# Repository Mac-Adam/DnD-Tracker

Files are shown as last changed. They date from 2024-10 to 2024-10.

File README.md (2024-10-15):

# DnD-Tracker
Repository for my resource tracker for D&amp;D
The premise of this project is to make keeping track of health, spell slots, and other resources quick and simple,
while preserving the vibe of an ttrpg.
It consists of 3 modules. One, keeps track of your health (3 led strips each one representing one digit of a 3 digit number)
Second one keeps track of your spell slots
The last one keeps track of whatever 20 resources you have, potions class features, magic items etc.
The rgb leds are driven by a 555 timer based circuit, this allows for controlling the color and brightness of the lights.
A standard 18650 cell is enough to power it for tens of hours (depending on the brightness level)
This project is not yet fully finished, the pcb and the files contain some errors that I haven't fixed yet.
The errors are:
  - Didn't reverse the logic of the LED ON button, insead of turning the leds off, it blasts them at full power
  - Transistors in one of the signal reperaters in the HP modules are switched (P is in flsae of N and N is in place of P)
  - The housing has misaligned mounting holes
## The Future
I might make the design modular, this would enable greater flexibility and probably would be cheaper.
Making the housing more practical and prettier.

If you want to build one of those yoursellf, but you encounter some problems with the provided files, contact me.

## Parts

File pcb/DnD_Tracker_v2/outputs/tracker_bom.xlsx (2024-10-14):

Qty | Designator | Footprint | Comment | LCSC Part #
3 | C1, C7, C11 | C2012 | 10n | C58456
141 | R3, R4, R5, R7, R8, R21, R29, R30, R32, R33, R35, R36, R38, R39, R41, R42, R61, R62, R64, R65, R67, R68, R89, R90, R93, R94, R96, R97, R113, R114, R115, R116, R125, R126, R128, R129, R138, R139, R140, R141, R144, R145, R147, R148, R152, R153, R155, R156, R158, R159, R167, R168, R170, R171, R173, R174, R179, R180, R182, R183, R185, R186, R188, R189, R191, R192, R194, R195, R203, R204, R206, R207, R217, R218, R220, R221, R231, R232, R234, R235, R245, R246, R257, R258, R260, R261, R269, R270, R272, R273, R283, R284, R286, R287, R297, R298, R300, R301, R311, R312, R320, R321, R323, R324, R326, R327, R329, R330, R332, R333, R335, R336, R338, R339, R341, R342, R344, R345, R347, R348, R350, R351, R353, R354, R356, R357, R359, R360, R362, R363, R365, R366, R368, R369, R371, R372, R374, R375, R379, R383, R387 | R0402 | 1k | C2991282
179 | R1, R2, R6, R9, R10, R11, R12, R13, R14, R15, R16, R28, R31, R34, R37, R40, R57, R58, R59, R60, R63, R66, R69, R70, R85, R86, R87, R88, R91, R92, R95, R98, R117, R118, R119, R120, R121, R122, R123, R124, R127, R134, R137, R142, R143, R146, R149, R150, R151, R154, R157, R160, R161, R162, R163, R164, R165, R166, R169, R172, R175, R176, R177, R178, R181, R184, R187, R190, R193, R196, R197, R198, R199, R200, R201, R202, R205, R208, R209, R210, R211, R212, R213, R214, R215, R216, R219, R222, R223, R224, R225, R226, R227, R228, R229, R230, R233, R236, R237, R238, R239, R240, R241, R242, R243, R244, R247, R248, R249, R250, R251, R252, R253, R254, R255, R256, R259, R262, R263, R264, R265, R266, R267, R268, R271, R274, R275, R276, R277, R278, R279, R280, R281, R282, R285, R288, R289, R290, R291, R292, R293, R294, R295, R296, R299, R302, R303, R304, R305, R306, R307, R308, R309, R310, R313, R314, R315, R316, R317, R318, R319, R322, R325, R328, R331, R334, R337, R340, R343, R346, R349, R352, R355, R358, R361, R364, R367, R370, R373 | R0402 | 1k5 | C409724
3 | C4, C8, C12 | C3216 | 470p | C309496
15 | U$4, U$36, U$99, U$148, U$166, U$181, U$196, U$211, U$224, U$239, U$249, U$262, U$277, U$292, U$307 | TSSOP14 | 74HC02PW,118 | C113211
27 | U$9, U$10, U$62, U$63, U$125, U$126, U$158, U$159, U$171, U$172, U$186, U$187, U$201, U$202, U$215, U$229, U$230, U$243, U$254, U$255, U$267, U$268, U$282, U$283, U$297, U$298, U$311 | SOT323 | BAW56W,115 | C426777
33 | U$5, U$6, U$57, U$59, U$100, U$101, U$150, U$153, U$167, U$168, U$182, U$183, U$197, U$198, U$212, U$213, U$225, U$226, U$240, U$241, U$250, U$251, U$263, U$264, U$278, U$279, U$293, U$294, U$308, U$309, U$332, U$336, U$340 | SOT323 | BAV99W | C2836068
3 | IC2, IC4, IC6 | SO08 | NE555 | C18164403
30 | U$7, U$8, U$60, U$61, U$102, U$124, U$154, U$157, U$169, U$170, U$184, U$185, U$199, U$200, U$214, U$220, U$227, U$228, U$242, U$248, U$252, U$253, U$265, U$266, U$280, U$281, U$295, U$296, U$310, U$316 | SMD_MICROSWITCH | YTSD003A0502502B | C2844401
69 | U$24, U$26, U$28, U$30, U$32, U$33, U$38, U$40, U$44, U$65, U$67, U$69, U$72, U$73, U$88, U$90, U$92, U$94, U$96, U$104, U$107, U$109, U$111, U$113, U$115, U$117, U$119, U$121, U$123, U$129, U$131, U$133, U$134, U$136, U$138, U$141, U$142, U$145, U$146, U$149, U$152, U$156, U$162, U$163, U$175, U$176, U$190, U$191, U$205, U$206, U$217, U$233, U$234, U$245, U$258, U$259, U$271, U$272, U$286, U$287, U$301, U$302, U$313, U$318, U$320, U$322, U$324, U$326, U$328 | BIG_SMD_LED | TC5050RGB_LED | C784540
30 | U$1, U$2, U$3, U$35, U$97, U$98, U$165, U$179, U$180, U$194, U$195, U$209, U$210, U$219, U$222, U$223, U$237, U$238, U$247, U$261, U$275, U$276, U$290, U$291, U$305, U$306, U$315, U$331, U$335, U$339 | SOT23 | SI2301 | C306861
51 | U$20, U$31, U$34, U$70, U$71, U$74, U$75, U$127, U$132, U$135, U$160, U$161, U$164, U$173, U$174, U$177, U$178, U$188, U$189, U$192, U$193, U$203, U$204, U$207, U$208, U$216, U$218, U$221, U$231, U$232, U$235, U$236, U$244, U$246, U$256, U$257, U$260, U$269, U$270, U$273, U$274, U$284, U$285, U$288, U$289, U$299, U$300, U$303, U$304, U$312, U$314 | SOT23 | SI2302S | C20628872

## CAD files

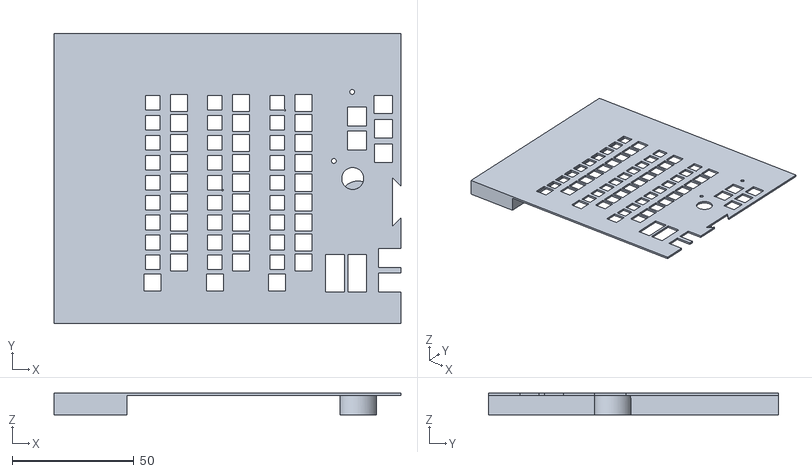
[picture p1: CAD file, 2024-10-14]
housing/top_right.stl
142.3 x 119.0 x 9.00

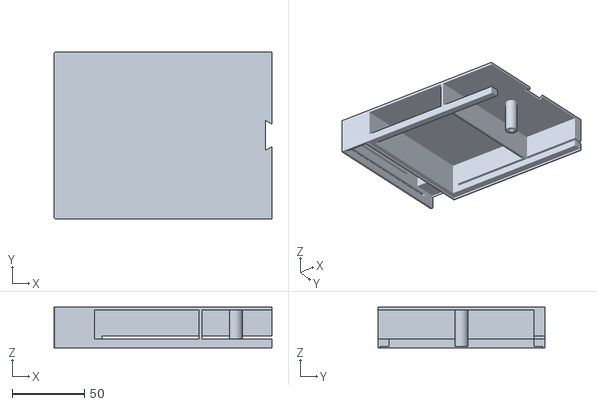
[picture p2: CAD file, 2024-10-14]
housing/base_right.stl
150.5 x 115.0 x 28.0

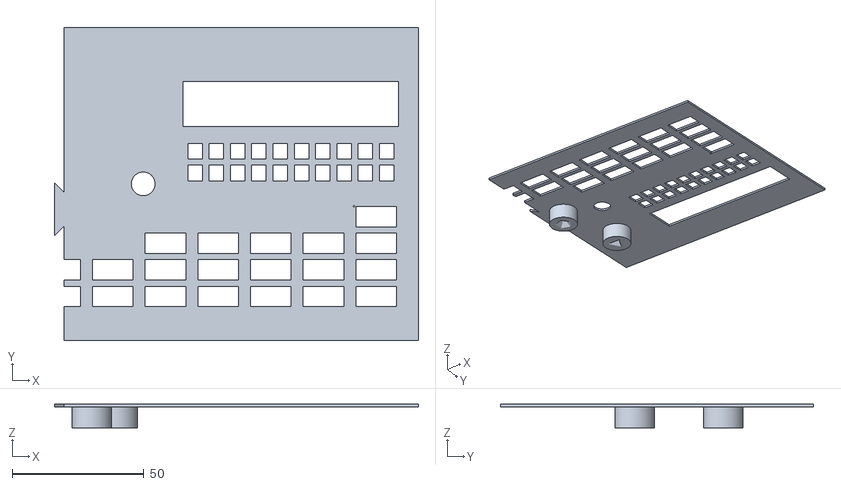
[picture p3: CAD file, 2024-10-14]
housing/top_left.stl
138.2 x 119.0 x 9.00

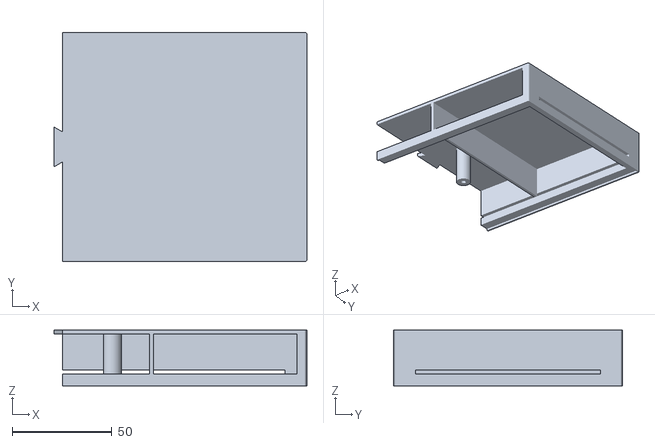
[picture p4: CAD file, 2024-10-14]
housing/base_left.stl
126.9 x 115.0 x 28.0

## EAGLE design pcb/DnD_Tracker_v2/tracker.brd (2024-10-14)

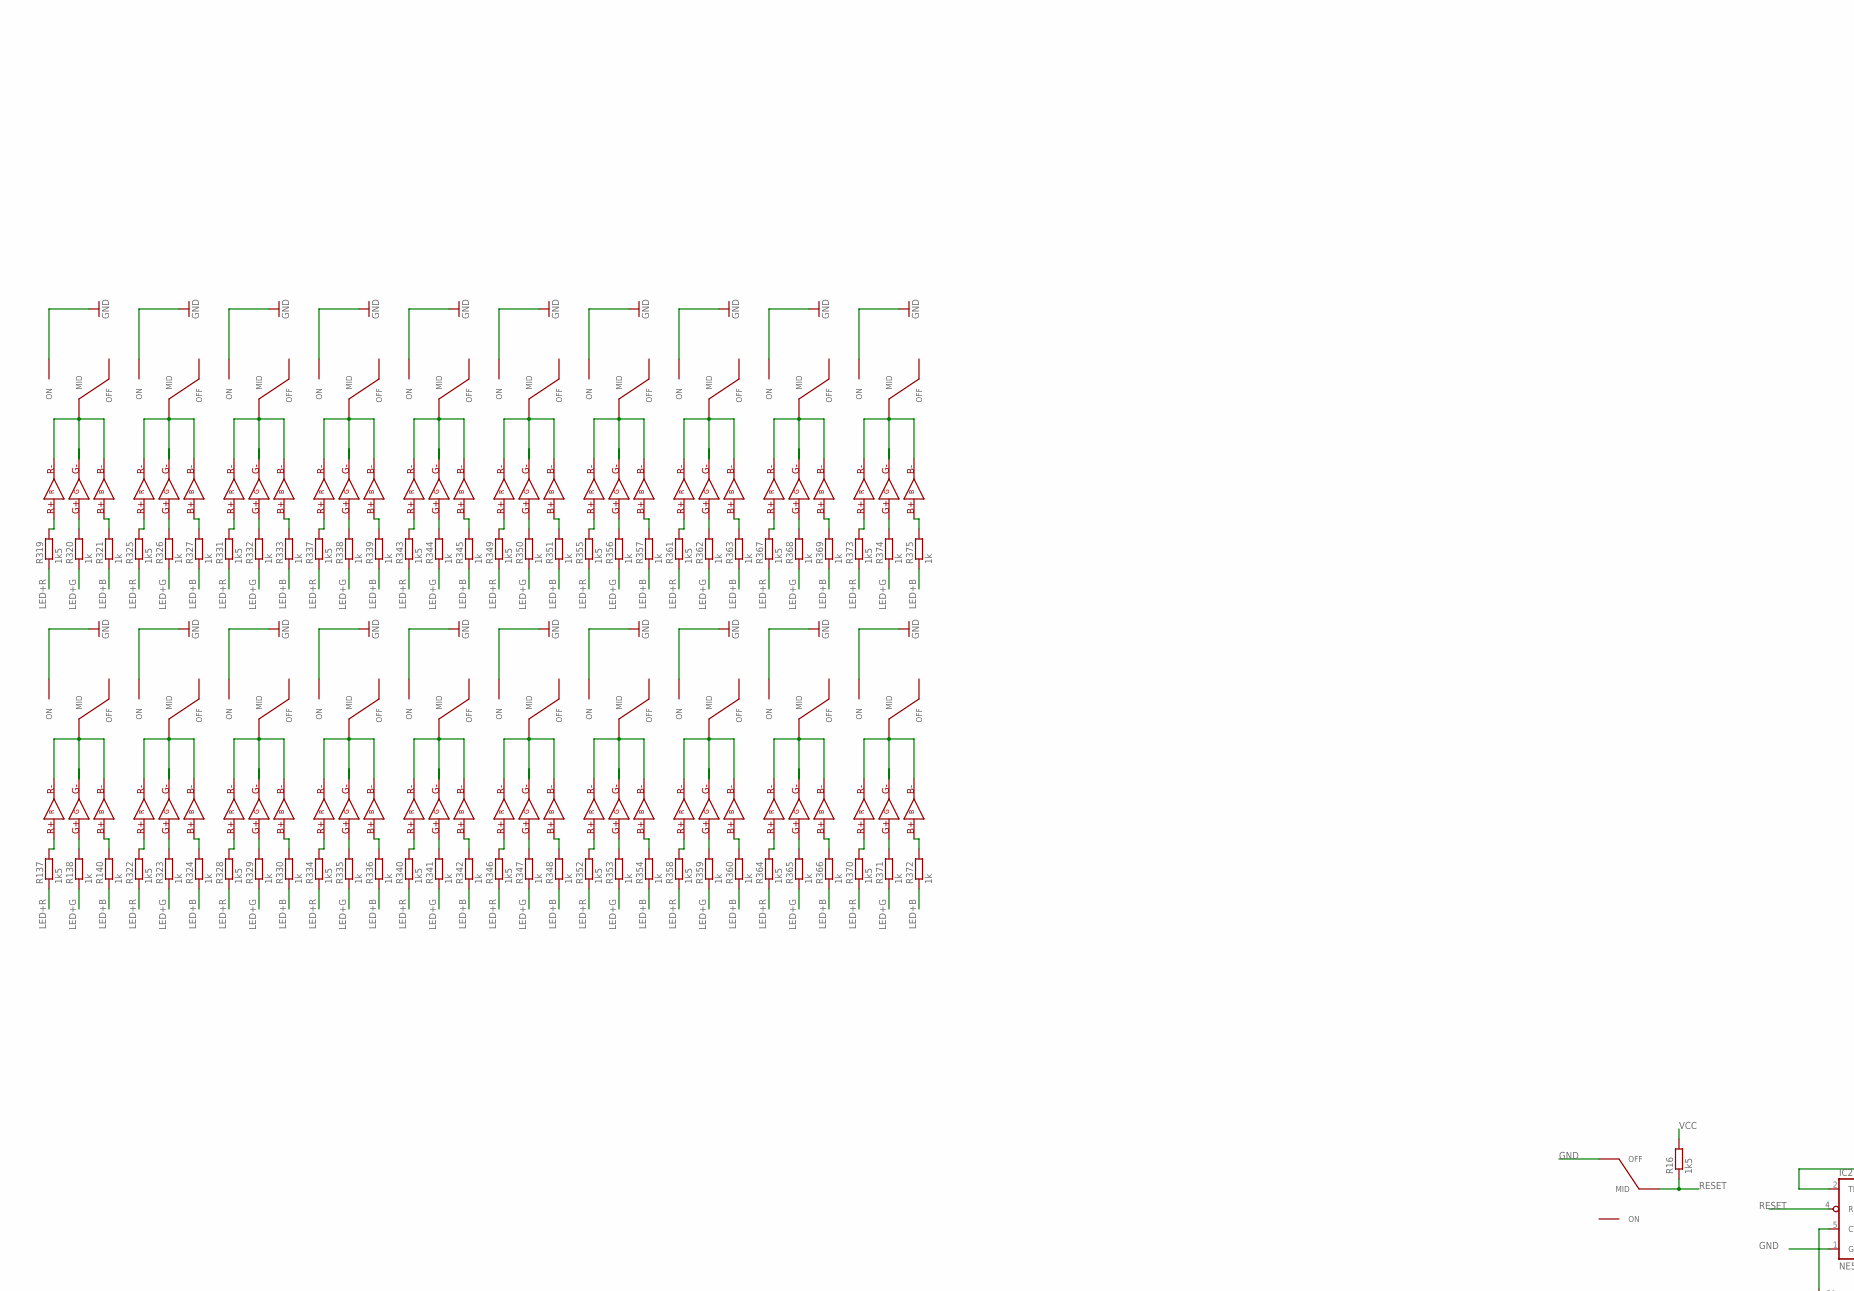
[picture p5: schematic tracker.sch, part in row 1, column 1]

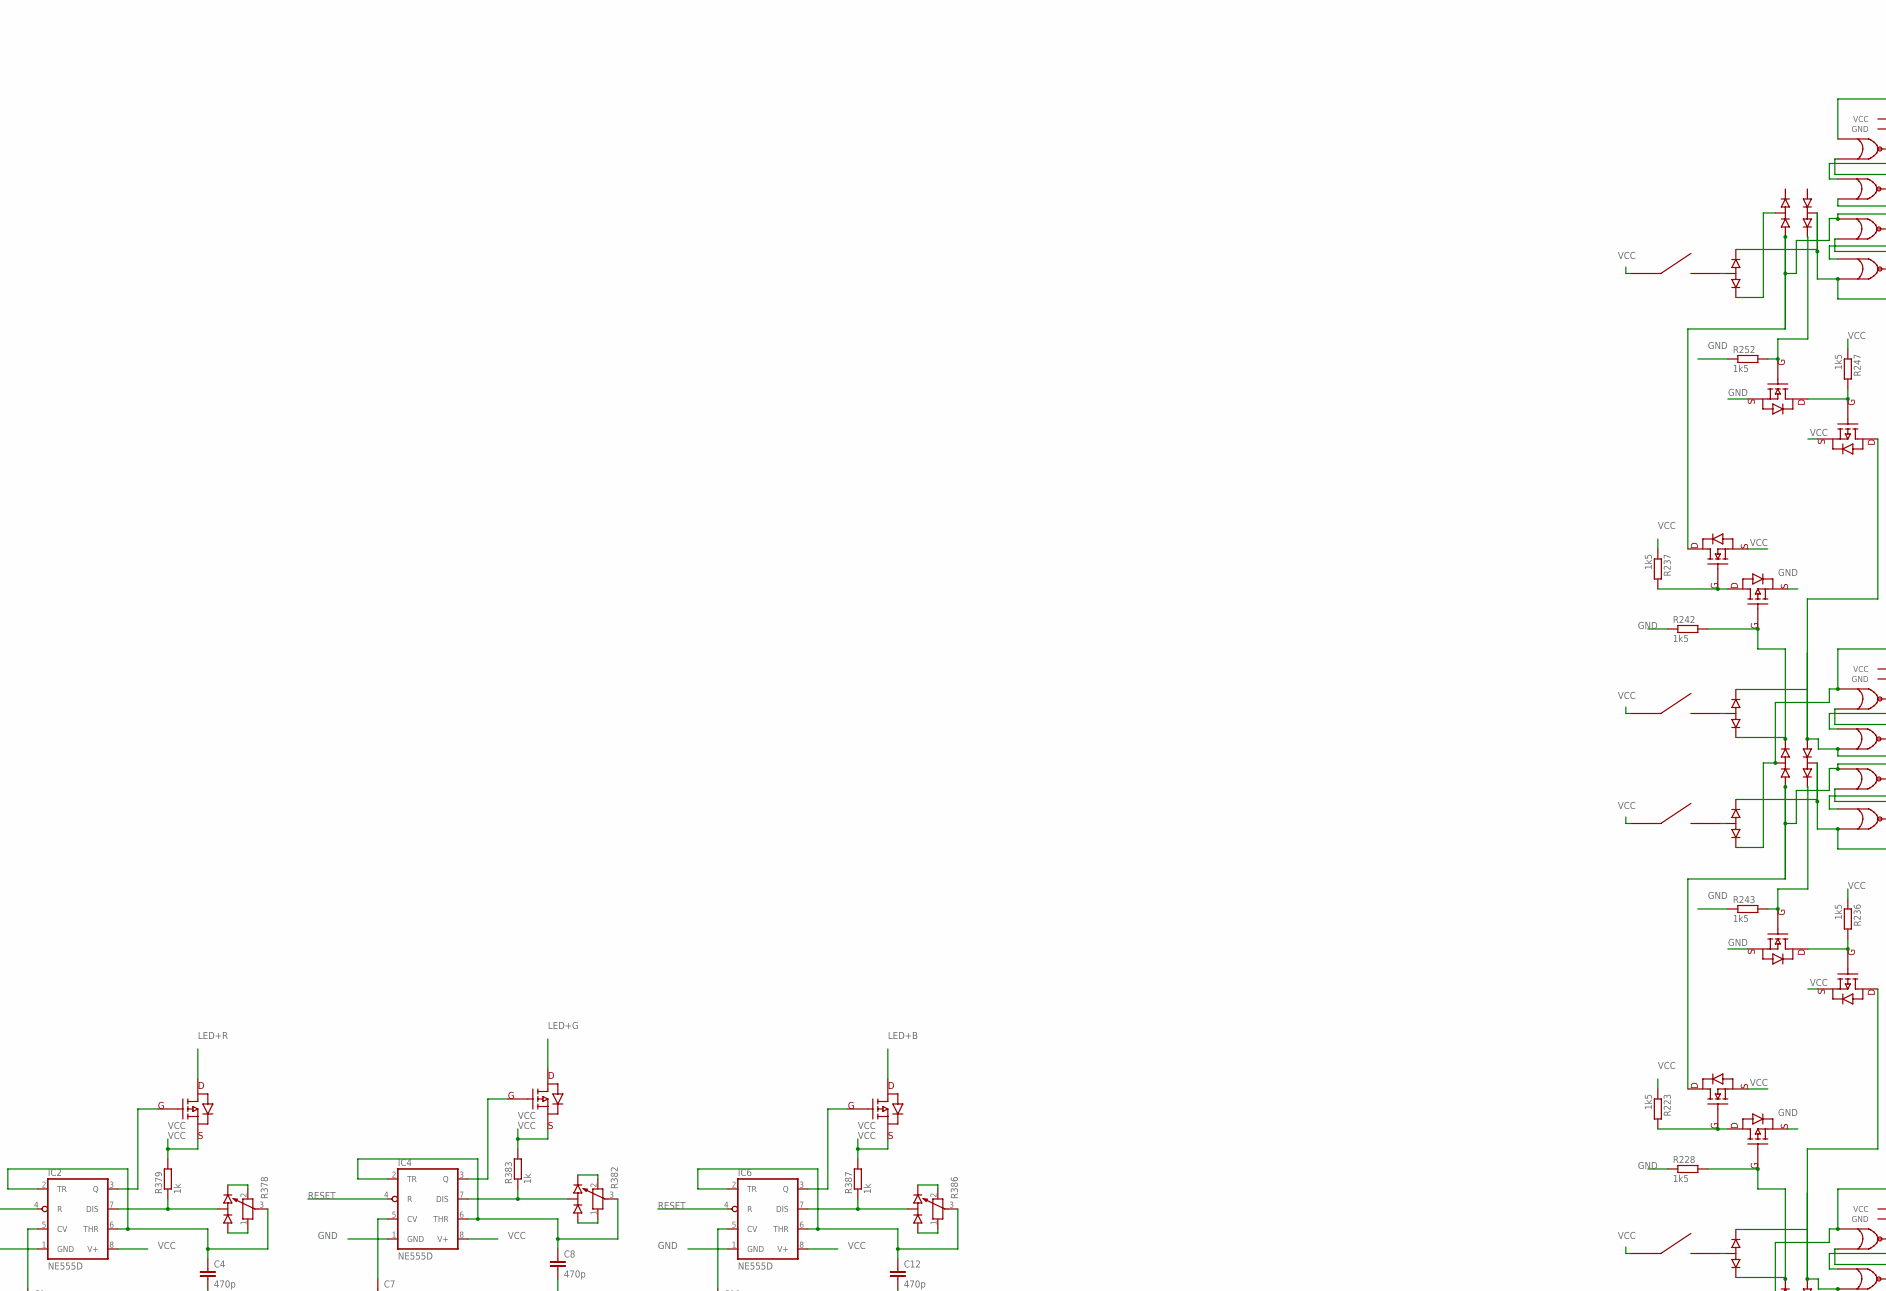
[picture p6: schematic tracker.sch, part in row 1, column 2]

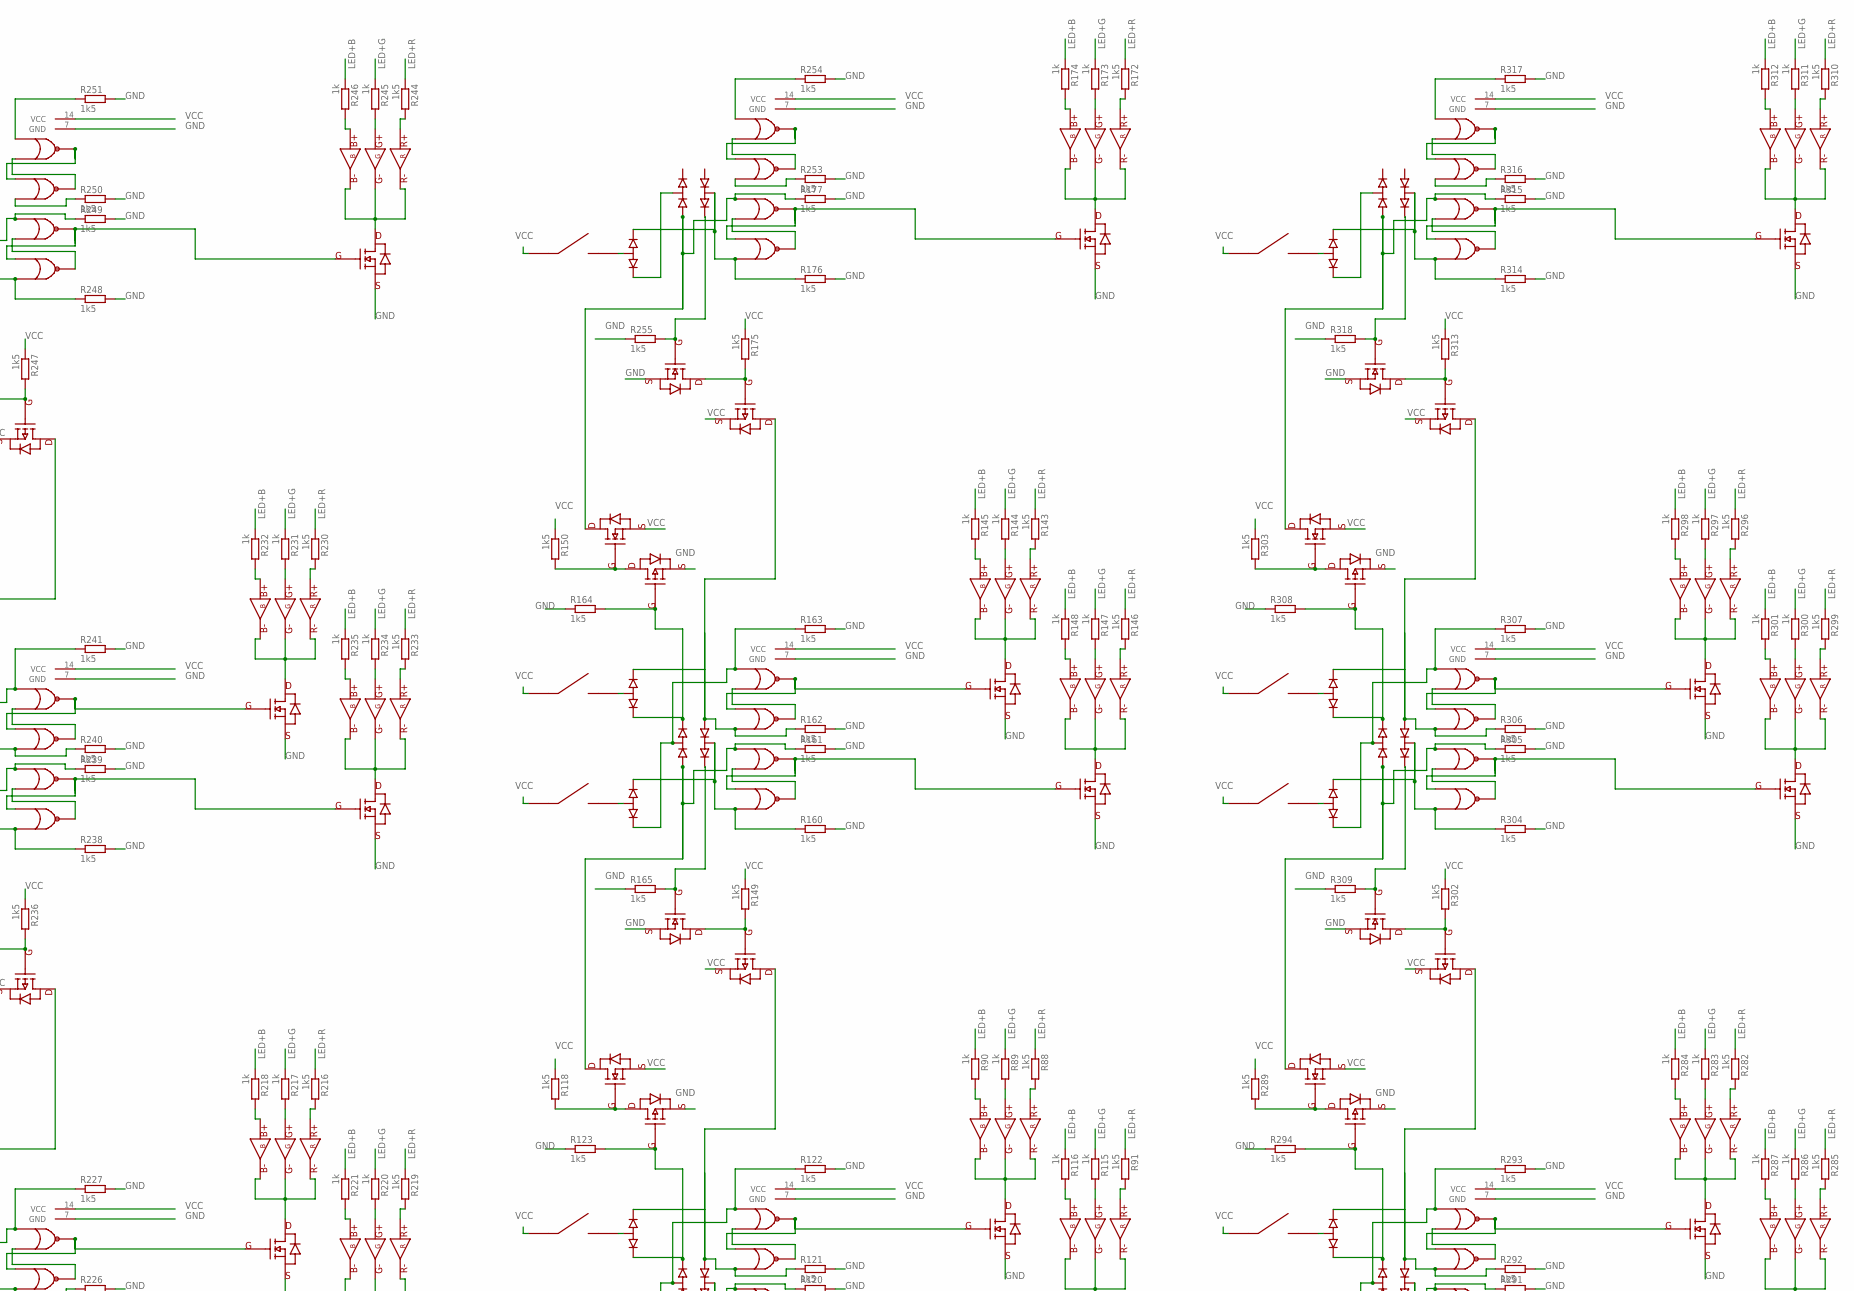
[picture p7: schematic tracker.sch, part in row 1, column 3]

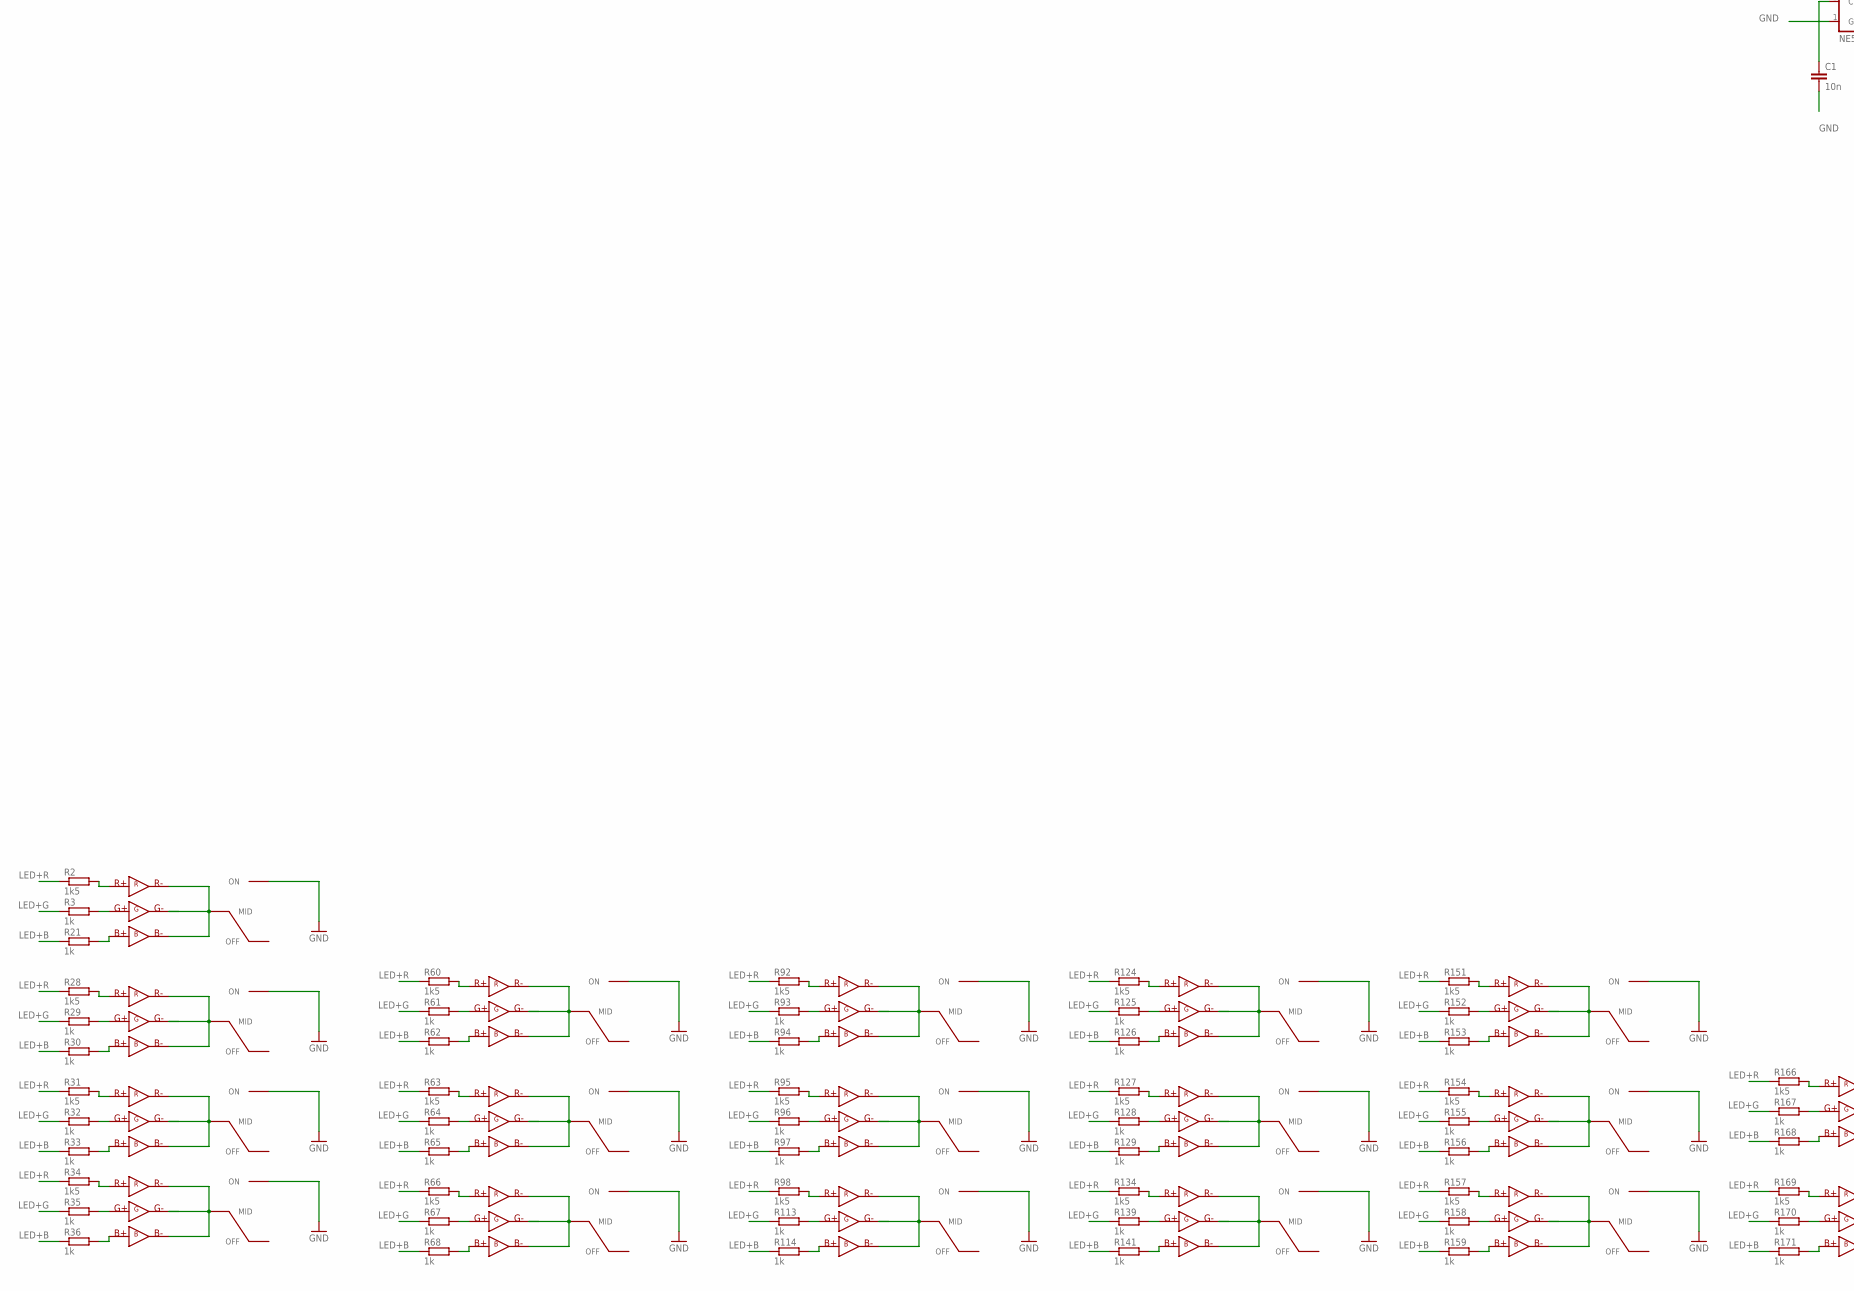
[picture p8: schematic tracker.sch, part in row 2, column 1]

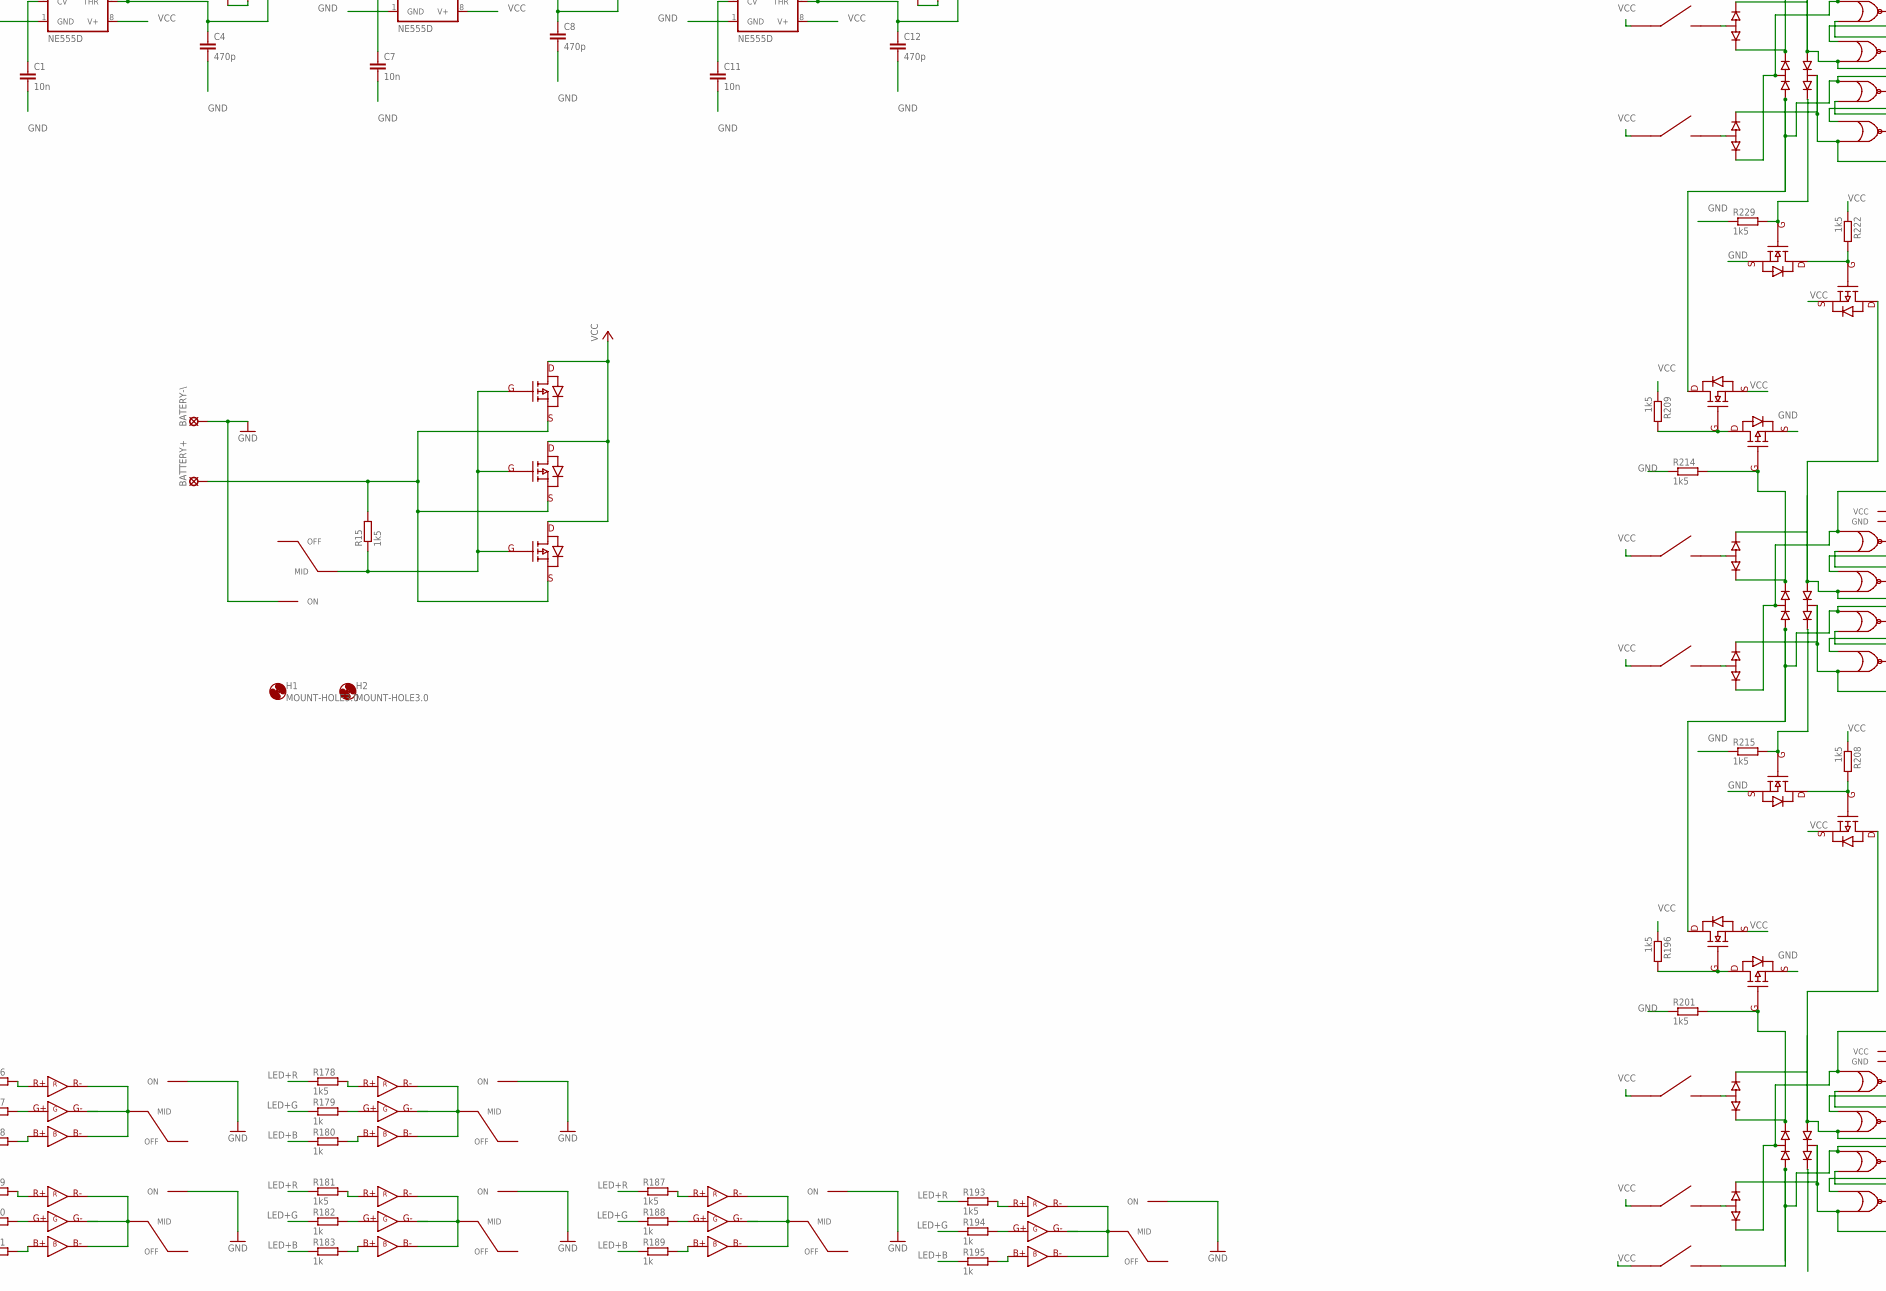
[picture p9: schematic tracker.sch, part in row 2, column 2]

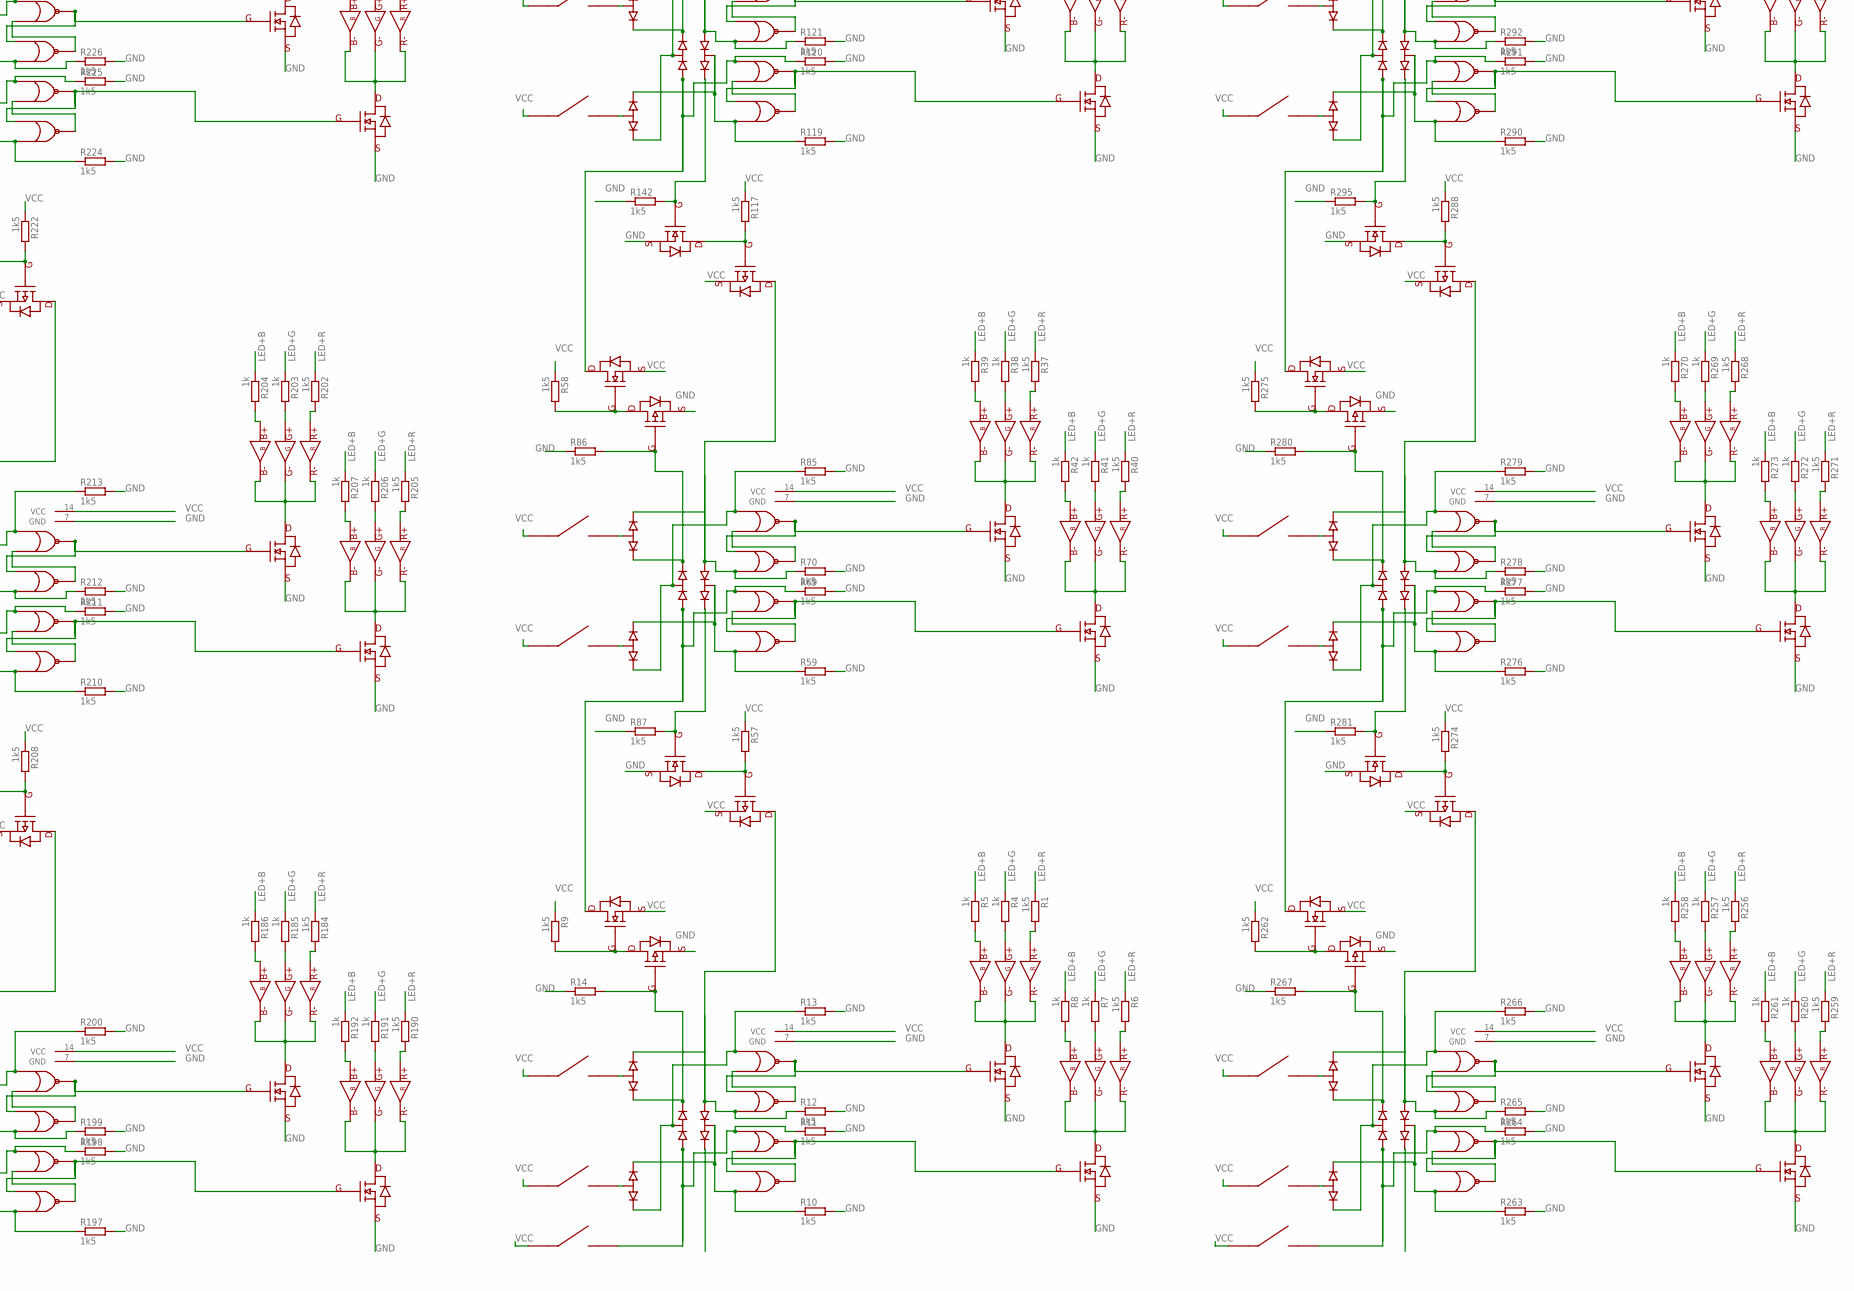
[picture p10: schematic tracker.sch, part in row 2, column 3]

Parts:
BATERY-\: LSP10
BATTERY+: LSP10
C1, C7, C11: 10n; C2012
C4, C8, C12: 470p; C3216
H1, H2: MOUNT-HOLE3.0; 3,0
IC2, IC4, IC6: NE555D; SO08
R1, R2, R6, R9, R10, R11, R12, R13, R14, R15, R16, R28, R31, R34, R37, R40, R57, R58, R59, R60, R63, R66, R69, R70, R85, R86, R87, R88, R91, R92, R95, R98, R117, R118, R119, R120, R121, R122, R123, R124, R127, R134, R137, R142, R143, R146, R149, R150, R151, R154, R157, R160, R161, R162, R163, R164, R165, R166, R169, R172, R175, R176, R177, R178, R181, R184, R187, R190, R193, R196, R197, R198, R199, R200, R201, R202, R205, R208, R209, R210, R211, R212, R213, R214, R215, R216, R219, R222, R223, R224, R225, R226, R227, R228, R229, R230, R233, R236, R237, R238, R239, R240, R241, R242, R243, R244, R247, R248, R249, R250, R251, R252, R253, R254, R255, R256, R259, R262, R263, R264, R265, R266, R267, R268, R271, R274, R275, R276, R277, R278, R279, R280, R281, R282, R285, R288, R289, R290, R291, R292, R293, R294, R295, R296, R299, R302, R303, R304, R305, R306, R307, R308, R309, R310, R313, R314, R315, R316, R317, R318, R319, R322, R325, R328, R331, R334, R337, R340, R343, R346, R349, R352, R355, R358, R361, R364, R367, R370, R373: 1k5; R0402
R3, R4, R5, R7, R8, R21, R29, R30, R32, R33, R35, R36, R38, R39, R41, R42, R61, R62, R64, R65, R67, R68, R89, R90, R93, R94, R96, R97, R113, R114, R115, R116, R125, R126, R128, R129, R138, R139, R140, R141, R144, R145, R147, R148, R152, R153, R155, R156, R158, R159, R167, R168, R170, R171, R173, R174, R179, R180, R182, R183, R185, R186, R188, R189, R191, R192, R194, R195, R203, R204, R206, R207, R217, R218, R220, R221, R231, R232, R234, R235, R245, R246, R257, R258, R260, R261, R269, R270, R272, R273, R283, R284, R286, R287, R297, R298, R300, R301, R311, R312, R320, R321, R323, R324, R326, R327, R329, R330, R332, R333, R335, R336, R338, R339, R341, R342, R344, R345, R347, R348, R350, R351, R353, R354, R356, R357, R359, R360, R362, R363, R365, R366, R368, R369, R371, R372, R374, R375, R379, R383, R387: 1k; R0402
R378, R382, R386: POTENTIOMETER_PT-10; PT-10
U$1, U$2, U$3, U$35, U$97, U$98, U$165, U$179, U$180, U$194, U$195, U$209, U$210, U$219, U$222, U$223, U$237, U$238, U$247, U$261, U$275, U$276, U$290, U$291, U$305, U$306, U$315, U$331, U$335, U$339: YJL2301D_PMOSFET; SOT23
U$4, U$36, U$99, U$148, U$166, U$181, U$196, U$211, U$224, U$239, U$249, U$262, U$277, U$292, U$307: 74HC02PW_QUAD_NOR; TSSOP14
U$5, U$6, U$57, U$59, U$100, U$101, U$150, U$153, U$167, U$168, U$182, U$183, U$197, U$198, U$212, U$213, U$225, U$226, U$240, U$241, U$250, U$251, U$263, U$264, U$278, U$279, U$293, U$294, U$308, U$309, U$332, U$336, U$340: BAT54SW_SERIES_DIODES; SOT323
U$7, U$8, U$60, U$61, U$102, U$124, U$154, U$157, U$169, U$170, U$184, U$185, U$199, U$200, U$214, U$220, U$227, U$228, U$242, U$248, U$252, U$253, U$265, U$266, U$280, U$281, U$295, U$296, U$310, U$316: SMD_MOCROSWITCH; SMD_MICROSWITCH
U$9, U$10, U$62, U$63, U$125, U$126, U$158, U$159, U$171, U$172, U$186, U$187, U$201, U$202, U$215, U$229, U$230, U$243, U$254, U$255, U$267, U$268, U$282, U$283, U$297, U$298, U$311: BAT5406W_COMON_CATHODE_DIODES; SOT323
U$11, U$12, U$22, U$25, U$27, U$29, U$37, U$39, U$43, U$64, U$66, U$68, U$87, U$89, U$91, U$93, U$95, U$103, U$105, U$106, U$108, U$110, U$112, U$114, U$116, U$118, U$120, U$122, U$128, U$130, U$137, U$139, U$140, U$143, U$144, U$147, U$151, U$155, U$317, U$319, U$321, U$323, U$325, U$327: BISTABLESWITCH; BISTABLE_SWITCH
U$20, U$31, U$34, U$70, U$71, U$74, U$75, U$127, U$132, U$135, U$160, U$161, U$164, U$173, U$174, U$177, U$178, U$188, U$189, U$192, U$193, U$203, U$204, U$207, U$208, U$216, U$218, U$221, U$231, U$232, U$235, U$236, U$244, U$246, U$256, U$257, U$260, U$269, U$270, U$273, U$274, U$284, U$285, U$288, U$289, U$299, U$300, U$303, U$304, U$312, U$314: YJL2304A_NMOSFET; SOT23@1
U$24, U$26, U$28, U$30, U$32, U$33, U$38, U$40, U$44, U$65, U$67, U$69, U$72, U$73, U$88, U$90, U$92, U$94, U$96, U$104, U$107, U$109, U$111, U$113, U$115, U$117, U$119, U$121, U$123, U$129, U$131, U$133, U$134, U$136, U$138, U$141, U$142, U$145, U$146, U$149, U$152, U$156, U$162, U$163, U$175, U$176, U$190, U$191, U$205, U$206, U$217, U$233, U$234, U$245, U$258, U$259, U$271, U$272, U$286, U$287, U$301, U$302, U$313, U$318, U$320, U$322, U$324, U$326, U$328: TC5050RGB_LED; BIG_SMD_LED

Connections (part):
CARRY_RESET_IN2: R198.1, U$148.8 (A3), U$150.1WIDEL (IN), U$220.3 (2), U$220.4 (2)
CARRY_RESET_IN3: R11.1, U$4.8 (A3), U$5.1WIDEL (IN), U$248.3 (2), U$248.4 (2)
CARRY_RESET_IN4: R264.1, U$249.8 (A3), U$250.1WIDEL (IN), U$316.3 (2), U$316.4 (2)
CARRY_RESET_OUT2: R211.1, U$164.SINGLE1 (D), U$166.8 (A3), U$167.1WIDEL (IN)
CARRY_RESET_OUT4: R225.1, U$178.SINGLE1 (D), U$181.8 (A3), U$182.1WIDEL (IN)
CARRY_RESET_OUT6: R239.1, U$193.SINGLE1 (D), U$196.8 (A3), U$197.1WIDEL (IN)
CARRY_RESET_OUT8: R249.1, U$208.SINGLE1 (D), U$211.8 (A3), U$212.1WIDEL (IN)
CARRY_RESET_OUT9: R69.1, U$34.SINGLE1 (D), U$36.8 (A3), U$57.1WIDEL (IN)
CARRY_RESET_OUT10: R120.1, U$75.SINGLE1 (D), U$99.8 (A3), U$100.1WIDEL (IN)
CARRY_RESET_OUT11: R161.1, U$221.SINGLE1 (D), U$224.8 (A3), U$225.1WIDEL (IN)
CARRY_RESET_OUT12: R177.1, U$236.SINGLE1 (D), U$239.8 (A3), U$240.1WIDEL (IN)
CARRY_RESET_OUT13: R277.1, U$260.SINGLE1 (D), U$262.8 (A3), U$263.1WIDEL (IN)
CARRY_RESET_OUT14: R291.1, U$274.SINGLE1 (D), U$277.8 (A3), U$278.1WIDEL (IN)
CARRY_RESET_OUT15: R305.1, U$289.SINGLE1 (D), U$292.8 (A3), U$293.1WIDEL (IN)
CARRY_RESET_OUT16: R315.1, U$304.SINGLE1 (D), U$307.8 (A3), U$308.1WIDEL (IN)
CARRY_SET_IN1: R250.1, U$211.6 (B2)
CARRY_SET_IN2: R253.1, U$239.6 (B2)
CARRY_SET_IN3: R316.1, U$307.6 (B2)
CARRY_SET_OUT1: R199.1, U$148.6 (B2), U$153.1WIDEL (IN), U$158.2WIDER (OUT1), U$179.SINGLE1 (D)
CARRY_SET_OUT2: R212.1, U$166.6 (B2), U$168.1WIDEL (IN), U$171.2WIDER (OUT1), U$194.SINGLE1 (D)
CARRY_SET_OUT4: R226.1, U$181.6 (B2), U$183.1WIDEL (IN), U$186.2WIDER (OUT1), U$209.SINGLE1 (D)
CARRY_SET_OUT6: R240.1, U$196.6 (B2), U$198.1WIDEL (IN), U$201.2WIDER (OUT1), U$219.SINGLE1 (D)
CARRY_SET_OUT8: R12.1, U$4.6 (B2), U$6.1WIDEL (IN), U$9.2WIDER (OUT1), U$97.SINGLE1 (D)
CARRY_SET_OUT10: R70.1, U$36.6 (B2), U$59.1WIDEL (IN), U$62.2WIDER (OUT1), U$222.SINGLE1 (D)
CARRY_SET_OUT11: R121.1, U$99.6 (B2), U$101.1WIDEL (IN), U$125.2WIDER (OUT1), U$237.SINGLE1 (D)
CARRY_SET_OUT12: R162.1, U$224.6 (B2), U$226.1WIDEL (IN), U$229.2WIDER (OUT1), U$247.SINGLE1 (D)
CARRY_SET_OUT13: R265.1, U$249.6 (B2), U$251.1WIDEL (IN), U$254.2WIDER (OUT1), U$275.SINGLE1 (D)
CARRY_SET_OUT14: R278.1, U$262.6 (B2), U$264.1WIDEL (IN), U$267.2WIDER (OUT1), U$290.SINGLE1 (D)
CARRY_SET_OUT15: R292.1, U$277.6 (B2), U$279.1WIDEL (IN), U$282.2WIDER (OUT1), U$305.SINGLE1 (D)
CARRY_SET_OUT16: R306.1, U$292.6 (B2), U$294.1WIDEL (IN), U$297.2WIDER (OUT1), U$315.SINGLE1 (D)
ENB2: U$148.1 (Y1), U$148.5 (A2), U$160.WIDEL (G)
ENB4: U$166.1 (Y1), U$166.5 (A2), U$173.WIDEL (G)
ENB6: U$181.1 (Y1), U$181.5 (A2), U$188.WIDEL (G)
ENB8: U$196.1 (Y1), U$196.5 (A2), U$203.WIDEL (G)
ENB10: U$211.1 (Y1), U$211.5 (A2)
ENB11: U$4.1 (Y1), U$4.5 (A2), U$20.WIDEL (G)
ENB12: U$36.1 (Y1), U$36.5 (A2), U$70.WIDEL (G)
ENB13: U$99.1 (Y1), U$99.5 (A2), U$127.WIDEL (G)
ENB14: U$224.1 (Y1), U$224.5 (A2), U$231.WIDEL (G)
ENB15: U$239.1 (Y1), U$239.5 (A2)
ENB16: U$249.1 (Y1), U$249.5 (A2), U$256.WIDEL (G)
ENB17: U$262.1 (Y1), U$262.5 (A2), U$269.WIDEL (G)
ENB18: U$277.1 (Y1), U$277.5 (A2), U$284.WIDEL (G)
ENB19: U$292.1 (Y1), U$292.5 (A2), U$299.WIDEL (G)
ENB20: U$307.1 (Y1), U$307.5 (A2)
GND: BATERY-\.MP, C1.2, C4.2, C7.2, C8.2, C11.2, C12.2, IC2.1 (GND), IC4.1 (GND), IC6.1 (GND), R10.2, R11.2, R12.2, R13.2, R14.1, R59.2, R69.2, R70.2, R85.2, R86.1, R87.1, R119.2, R120.2, R121.2, R122.2, R123.1, R142.1, R160.2, R161.2, R162.2, R163.2, R164.1, R165.1, R176.2, R177.2, R197.2, R198.2, R199.2, R200.2, R201.1, R210.2, R211.2, R212.2, R213.2, R214.1, R215.1, R224.2, R225.2, R226.2, R227.2, R228.1, R229.1, R238.2, R239.2, R240.2, R241.2, R242.1, R243.1, R248.2, R249.2, R250.2, R251.2, R252.1, R253.2, R254.2, R255.1, R263.2, R264.2, R265.2, R266.2, R267.1, R276.2, R277.2, R278.2, R279.2, R280.1, R281.1, R290.2, R291.2, R292.2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
LED+B: R5.1, R8.1, R21.1, R30.1, R33.1, R36.1, R39.1, R42.1, R62.1, R65.1, R68.1, R90.1, R94.1, R97.1, R114.1, R116.1, R126.1, R129.1, R140.1, R141.1, R145.1, R148.1, R153.1, R156.1, R159.1, R168.1, R171.1, R174.1, R180.1, R183.1, R186.1, R189.1, R192.1, R195.1, R204.1, R207.1, R218.1, R221.1, R232.1, R235.1, R246.1, R258.1, R261.1, R270.1, R273.1, R284.1, R287.1, R298.1, R301.1, R312.1, R321.1, R324.1, R327.1, R330.1, R333.1, R336.1, R339.1, R342.1, R345.1, R348.1, R351.1, R354.1, R357.1, R360.1, R363.1, R366.1, R369.1, R372.1, R375.1, U$339.SINGLE1 (D)
LED+G: R3.1, R4.1, R7.1, R29.1, R32.1, R35.1, R38.1, R41.1, R61.1, R64.1, R67.1, R89.1, R93.1, R96.1, R113.1, R115.1, R125.1, R128.1, R138.1, R139.1, R144.1, R147.1, R152.1, R155.1, R158.1, R167.1, R170.1, R173.1, R179.1, R182.1, R185.1, R188.1, R191.1, R194.1, R203.1, R206.1, R217.1, R220.1, R231.1, R234.1, R245.1, R257.1, R260.1, R269.1, R272.1, R283.1, R286.1, R297.1, R300.1, R311.1, R320.1, R323.1, R326.1, R329.1, R332.1, R335.1, R338.1, R341.1, R344.1, R347.1, R350.1, R353.1, R356.1, R359.1, R362.1, R365.1, R368.1, R371.1, R374.1, U$335.SINGLE1 (D)
LED+R: R1.1, R2.1, R6.1, R28.1, R31.1, R34.1, R37.1, R40.1, R60.1, R63.1, R66.1, R88.1, R91.1, R92.1, R95.1, R98.1, R124.1, R127.1, R134.1, R137.1, R143.1, R146.1, R151.1, R154.1, R157.1, R166.1, R169.1, R172.1, R178.1, R181.1, R184.1, R187.1, R190.1, R193.1, R202.1, R205.1, R216.1, R219.1, R230.1, R233.1, R244.1, R256.1, R259.1, R268.1, R271.1, R282.1, R285.1, R296.1, R299.1, R310.1, R319.1, R322.1, R325.1, R328.1, R331.1, R334.1, R337.1, R340.1, R343.1, R346.1, R349.1, R352.1, R355.1, R358.1, R361.1, R364.1, R367.1, R370.1, R373.1, U$331.SINGLE1 (D)
N2: R201.2, U$150.2WIDER (OUT), U$158.1WIDEL (OUT2), U$165.WIDEL (G)
N4: R214.2, U$167.2WIDER (OUT), U$171.1WIDEL (OUT2), U$180.WIDEL (G)
N6: R228.2, U$182.2WIDER (OUT), U$186.1WIDEL (OUT2), U$195.WIDEL (G)
N8: R242.2, U$197.2WIDER (OUT), U$201.1WIDEL (OUT2), U$210.WIDEL (G)
N9: R14.2, U$5.2WIDER (OUT), U$9.1WIDEL (OUT2), U$35.WIDEL (G)
N10: R86.2, U$57.2WIDER (OUT), U$62.1WIDEL (OUT2), U$98.WIDEL (G)
N11: R123.2, U$100.2WIDER (OUT), U$125.1WIDEL (OUT2), U$223.WIDEL (G)
N12: R164.2, U$225.2WIDER (OUT), U$229.1WIDEL (OUT2), U$238.WIDEL (G)
N13: R267.2, U$250.2WIDER (OUT), U$254.1WIDEL (OUT2), U$261.WIDEL (G)
N14: R280.2, U$263.2WIDER (OUT), U$267.1WIDEL (OUT2), U$276.WIDEL (G)
N15: R294.2, U$278.2WIDER (OUT), U$282.1WIDEL (OUT2), U$291.WIDEL (G)
N16: R308.2, U$293.2WIDER (OUT), U$297.1WIDEL (OUT2), U$306.WIDEL (G)
unnamed: BATTERY+.MP, R15.2, U$1.WIDER (S), U$2.WIDER (S), U$3.WIDER (S)
unnamed: U$4.3 (B1), U$4.4 (Y2)
unnamed: U$4.9 (B3), U$4.13 (Y4)
unnamed: U$4.10 (Y3), U$4.11 (A4), U$31.WIDEL (G)
unnamed: R10.1, U$4.12 (B4), U$6.3SINGLE (MID), U$10.2WIDER (OUT1)
unnamed: U$7.3 (2), U$7.4 (2), U$9.3SINGLE (IN1)
unnamed: R15.1, U$1.WIDEL (G), U$2.WIDEL (G), U$3.WIDEL (G), U$11.A2 (MID), U$11.B2 (MID)
unnamed: U$8.3 (2), U$8.4 (2), U$10.3SINGLE (IN1)
unnamed: R13.1, U$4.2 (A1), U$5.3SINGLE (MID), U$10.1WIDEL (OUT2)
unnamed: R1.2, U$32.2 (RPLUS)
unnamed: R4.2, U$32.1 (GPLUS)
unnamed: R5.2, U$32.3 (BPLUS)
unnamed: U$20.SINGLE1 (D), U$32.4 (BMINUS), U$32.5 (RMINUS), U$32.6 (GMINUS)
unnamed: R6.2, U$33.2 (RPLUS)
unnamed: R7.2, U$33.1 (GPLUS)
unnamed: R8.2, U$33.3 (BPLUS)
unnamed: U$31.SINGLE1 (D), U$33.4 (BMINUS), U$33.5 (RMINUS), U$33.6 (GMINUS)
unnamed: R2.2, U$24.2 (RPLUS)
unnamed: R3.2, U$24.1 (GPLUS)
unnamed: R21.2, U$24.3 (BPLUS)
unnamed: U$22.A2 (MID), U$22.B2 (MID), U$24.4 (BMINUS), U$24.5 (RMINUS), U$24.6 (GMINUS)
unnamed: R28.2, U$26.2 (RPLUS)
unnamed: R29.2, U$26.1 (GPLUS)
unnamed: R30.2, U$26.3 (BPLUS)
unnamed: U$25.A2 (MID), U$25.B2 (MID), U$26.4 (BMINUS), U$26.5 (RMINUS), U$26.6 (GMINUS)
unnamed: R31.2, U$28.2 (RPLUS)
unnamed: R32.2, U$28.1 (GPLUS)
unnamed: R33.2, U$28.3 (BPLUS)
unnamed: U$27.A2 (MID), U$27.B2 (MID), U$28.4 (BMINUS), U$28.5 (RMINUS), U$28.6 (GMINUS)
unnamed: R34.2, U$30.2 (RPLUS)
unnamed: R35.2, U$30.1 (GPLUS)
unnamed: R36.2, U$30.3 (BPLUS)
unnamed: U$29.A2 (MID), U$29.B2 (MID), U$30.4 (BMINUS), U$30.5 (RMINUS), U$30.6 (GMINUS)
unnamed: R9.2, U$34.WIDEL (G), U$35.SINGLE1 (D)
unnamed: U$36.3 (B1), U$36.4 (Y2)
unnamed: U$36.9 (B3), U$36.13 (Y4)
unnamed: U$36.10 (Y3), U$36.11 (A4), U$71.WIDEL (G)
unnamed: R59.1, U$36.12 (B4), U$59.3SINGLE (MID), U$63.2WIDER (OUT1)
unnamed: U$60.3 (2), U$60.4 (2), U$62.3SINGLE (IN1)
unnamed: U$61.3 (2), U$61.4 (2), U$63.3SINGLE (IN1)
unnamed: R85.1, U$36.2 (A1), U$57.3SINGLE (MID), U$63.1WIDEL (OUT2)
unnamed: R37.2, U$72.2 (RPLUS)
unnamed: R38.2, U$72.1 (GPLUS)
unnamed: R39.2, U$72.3 (BPLUS)
unnamed: U$70.SINGLE1 (D), U$72.4 (BMINUS), U$72.5 (RMINUS), U$72.6 (GMINUS)
unnamed: R60.2, U$38.2 (RPLUS)
unnamed: R61.2, U$38.1 (GPLUS)
unnamed: R62.2, U$38.3 (BPLUS)
unnamed: U$37.A2 (MID), U$37.B2 (MID), U$38.4 (BMINUS), U$38.5 (RMINUS), U$38.6 (GMINUS)
unnamed: R63.2, U$40.2 (RPLUS)
unnamed: R64.2, U$40.1 (GPLUS)
unnamed: R65.2, U$40.3 (BPLUS)
unnamed: U$39.A2 (MID), U$39.B2 (MID), U$40.4 (BMINUS), U$40.5 (RMINUS), U$40.6 (GMINUS)
unnamed: R66.2, U$44.2 (RPLUS)
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

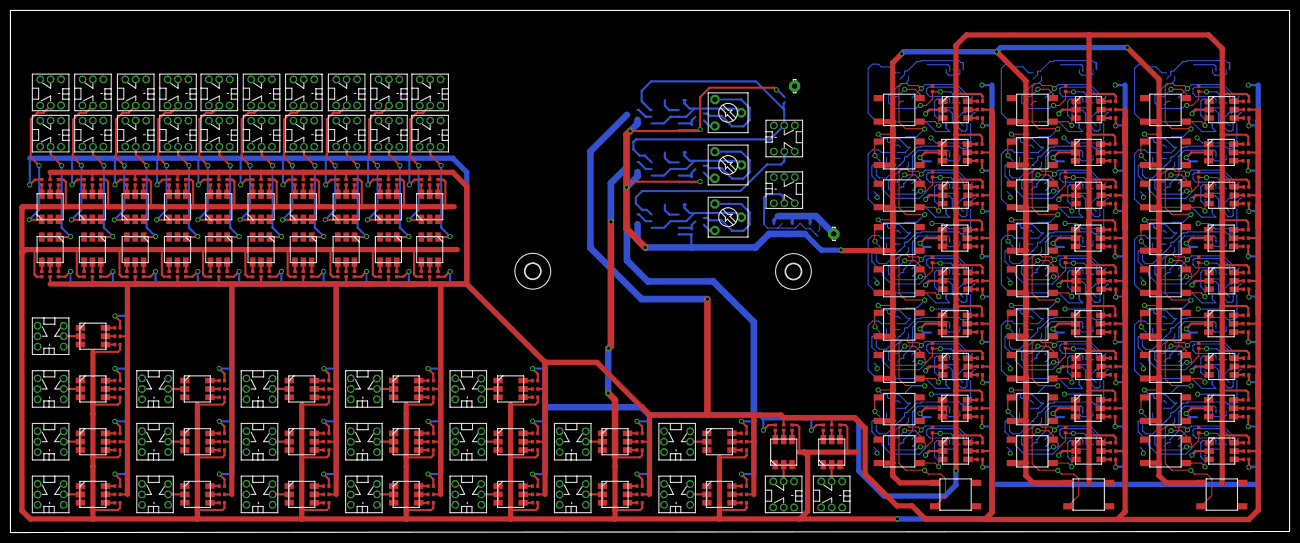
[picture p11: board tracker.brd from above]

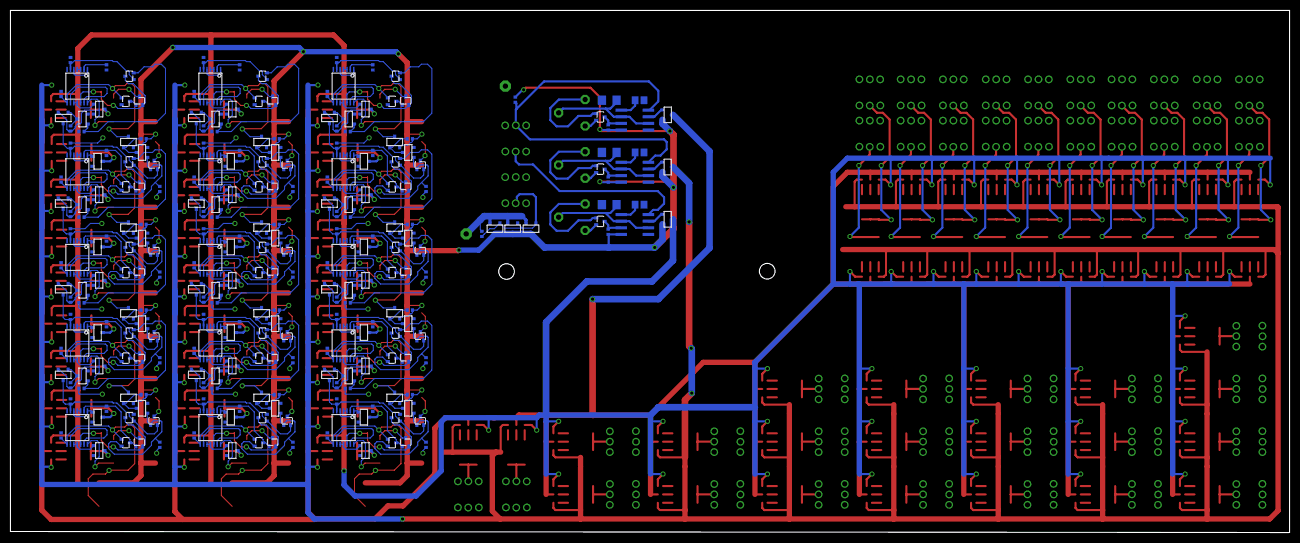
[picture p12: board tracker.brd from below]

Board: 2 copper layers, 245.0 x 100.0 mm, 635 parts (263 on the bottom side), 500 nets.
